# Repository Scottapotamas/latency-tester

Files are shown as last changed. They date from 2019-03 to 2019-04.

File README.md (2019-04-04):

# Latency Tester

Small and simple board to make testing response times easier. Its basically a nice switch, phototransistor and some LEDs with IO.

Intended to be used for measuring:

- Display input latency (switch to photon time)

- Micro/Computer communications latency (switch to serial, serial to photon, etc)

- "Whole chain" timing assessments (key-switch to photon while over communications link etc)
- Human response time tests? Press the button when the light comes on...

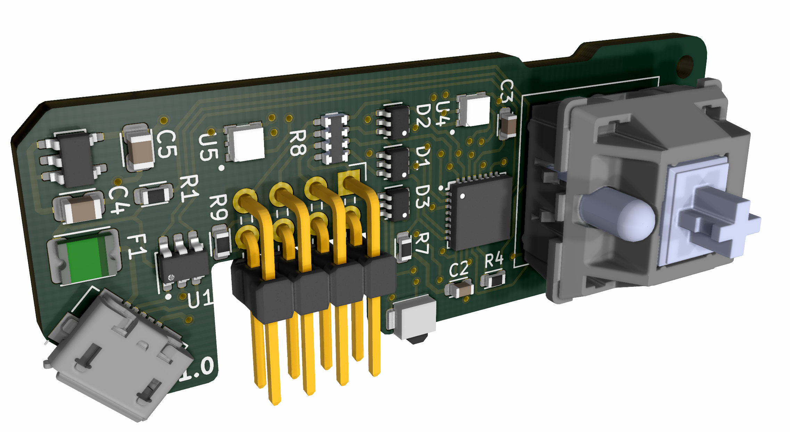
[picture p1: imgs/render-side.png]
render-side


## Electronics

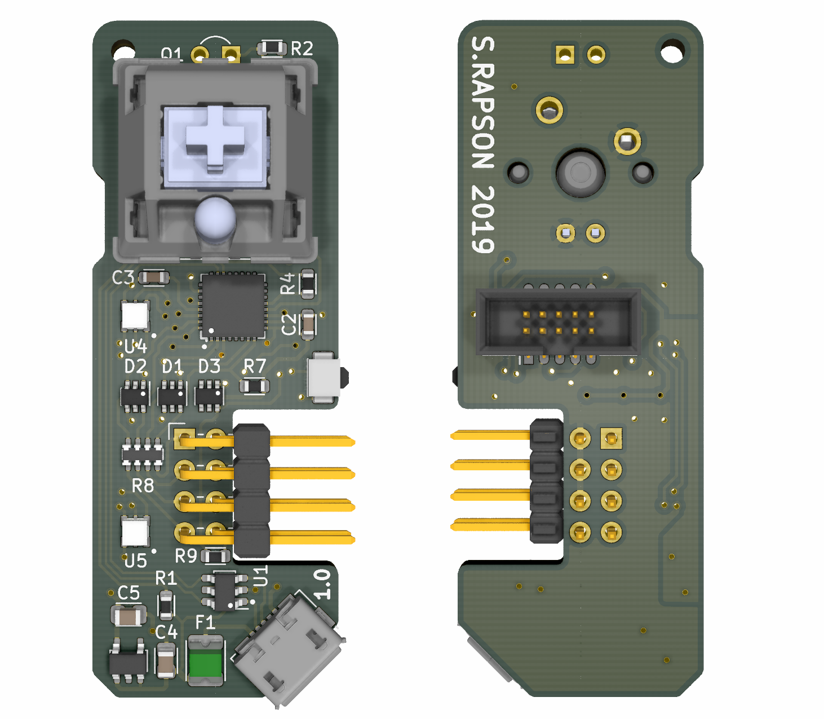
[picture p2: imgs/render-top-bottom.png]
render-top-bottom


- Board uses an ATSAMD M0 microcontroller. Intended for use with the Adafruit Trinket bootloader/ecosystem.

- Native USB means it can enumerate as a HID device, allowing use as a mouse/keyboard etc, or USB CDC.

- Cherry MX key-switch to act as the 'stimulus'. Photo-sensor to measure display changes as required.

- Expansion IO header provides hardware UART, along with 2 IO lines primarily intended to signal the stimulus and optical detection times. This 2x4 2.54mm header can be connected directly into a Saleae Logic analyser for timing analysis.

- 2x APA102 RGB Leds can be used to indicate state etc.
- 3mm LED in MX keyswitch is connected to the `LED_BUILTIN` pin for Arduino ecosystem, indicates bootloader state and can be used as generic user LED.
- Reset switch on bottom edge.
- SWD connector on rear isn't intended to be populated.

## Enclosure

Mostly designed to try some new modelling techniques and different enclosure approach. Intended for SLA 3D printing. I used [Lexcent](http://www.lexcent.com/).

Consists of two parts. Board slides into the halves, though some minor sanding/filing might be required depending on tolerances of SMD component placement.

I'll probably paint the 'bottom' part black, with the 'diffuse white' natural plastic allowing the top section to act as an illuminated highlight strip as depicted in the render.

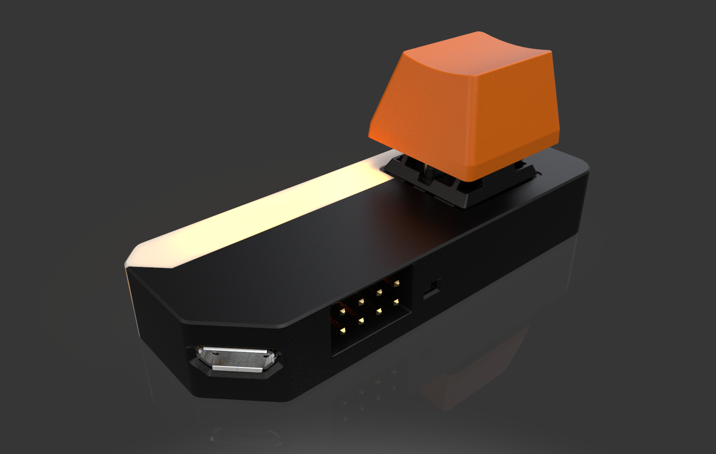
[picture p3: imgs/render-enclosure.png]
render-enclosure


## Firmware

TBD.

## Software

TBD

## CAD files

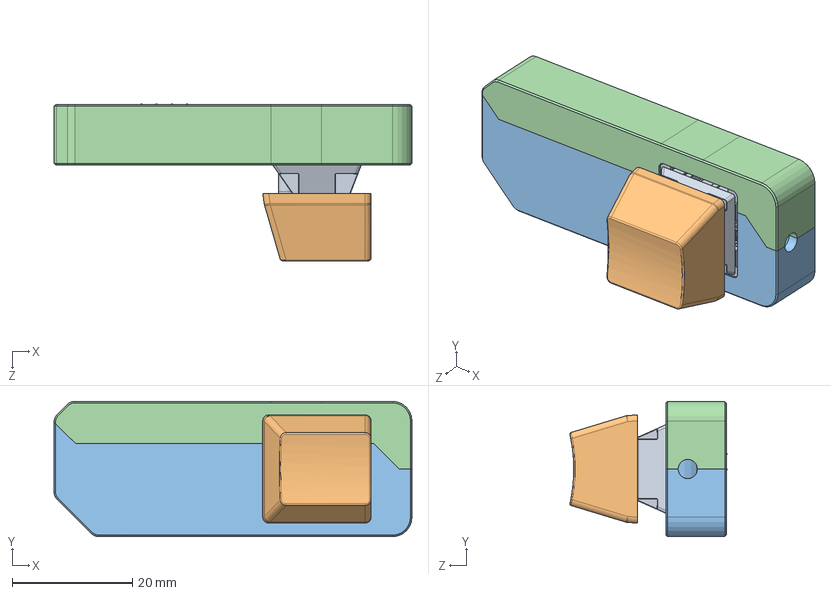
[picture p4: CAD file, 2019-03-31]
mcad/latency-tester-assy.SLDASM
59.5 x 22.5 x 26.2 mm
reflex_pcb
mx-keycap
shell-top

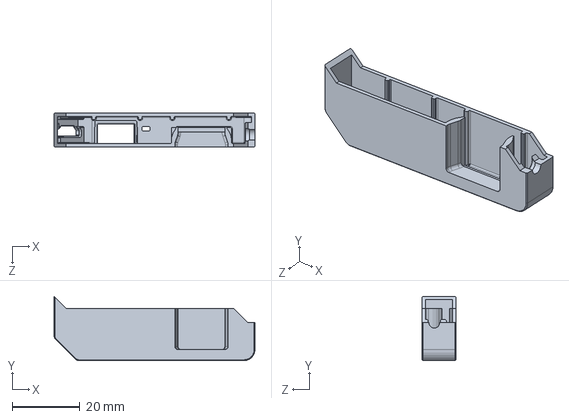
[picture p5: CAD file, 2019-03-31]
mcad/shell.SLDPRT
59.5 x 19.0 x 10.0 mm

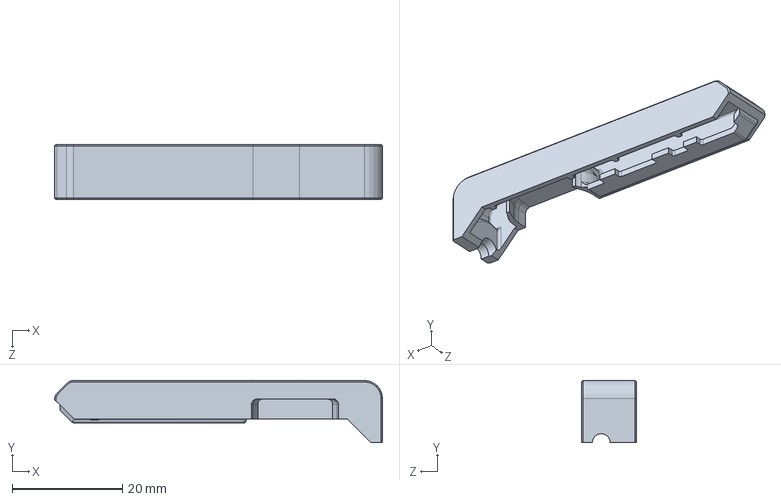
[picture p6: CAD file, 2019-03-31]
mcad/shell-top.SLDPRT
59.5 x 11.2 x 10.0 mm

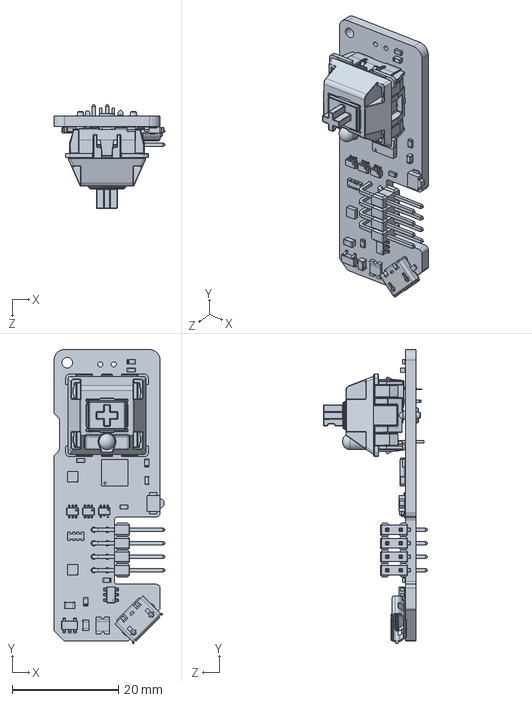
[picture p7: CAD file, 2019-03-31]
mcad/reflex_pcb.SLDPRT
20.9 x 55.4 x 19.6 mm

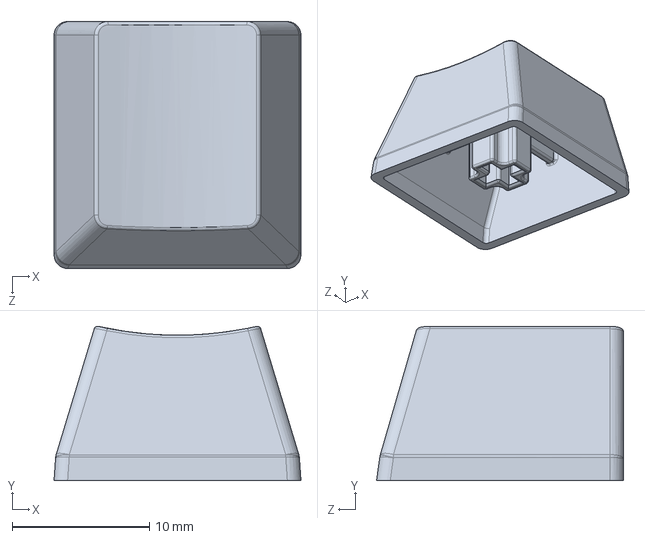
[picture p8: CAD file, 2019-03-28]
mcad/mx-keycap.SLDPRT
18.0 x 11.3 x 18.0 mm

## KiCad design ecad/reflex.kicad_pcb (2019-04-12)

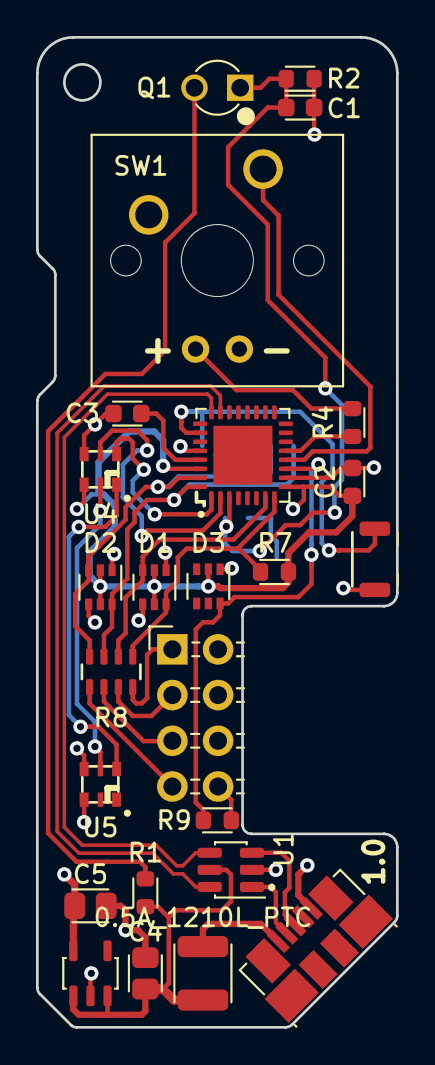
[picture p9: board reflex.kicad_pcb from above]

Board: 2 copper layers, 20.0 x 55.0 mm, 26 parts (1 on the bottom side), 29 nets.

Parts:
C1: 1n_X7R_1608M; CAPC1608X90N
C2: 1u_X7R_1608M; CAPC1608X90N
C3: 100n_X7R_1608M; CAPC1608X90N
C4, C5: 10u_X7R_2012M; CAPC2012X110N
D1, D2, D3: BAV99_DUAL; SOT-363-6N
F1: 0.5A_1210L_PTC; FUSC3225X85L50N
J1: USB_MICRO_B_SMD_2; MOLEX_47346-0001
J2: CONN_02X04_RA; CONN_02X04_RA_MALE
Q1: BPW85C; TRANS_BCW85
R1: 0R_1608M; RESC1608X50N
R2, R7: 10K0_1608M; RESC1608X50N
R4, R9: 1K50_1608M; RESC1608X50N
R8: 100R_QUAD_ARRAY_1608M; R_Array_Concave_4x1608M
SW1: CHERRY_MX1A-E1NW_BLUE; CHERRY_MX_PCB
SW2: B3U-3000P_SPST-NO_SMD; B3U-3000P
U1: USBLC6; SOT95P280X145-6L50N
U2: ATSAMD21E18A; QFN33P50_500X500X100L40X24T345N
U3: AP2112K-3.3; SOT95P280X145-5L30N
U4, U5: APA102-2020; AP102_200X200X90L
X1: SWD_SMT_SOCKET; CNCTECH_3220-10-0300-00

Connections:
+3.3V: C2.2, C5.1, D1.2, D1.5, D2.2, D2.5, D3.2, R7.2, U2.9, U2.30, U3.5, U4.5, U5.5, X1.1
+5V: C4.1, F1.1, R1.1, U1.5, U3.1, U3.3
EXTERNAL_TRIG: D3.6, R9.2, U2.11
GND: C1.2, C2.1, C3.1, C4.2, C5.2, D1.1, D1.4, D2.1, D2.4, D3.1, J1.5, J2.6, J2.7, J2.8, R2.1, SW1.2, SW1.4, SW2.1, U1.2, U2.10, U2.28, U3.2, U4.4, U5.4, X1.3, X1.5
LED_CLK: U2.2, U4.3
LED_DATA: U2.1, U4.2
unnamed: C3.2, U2.29
unnamed: F1.2, J1.1
unnamed: J1.2, U1.1
unnamed: J1.3, U1.3
unnamed: J2.1, R8.4
unnamed: J2.2, R8.3
unnamed: J2.3, R8.2
unnamed: J2.4, R8.1
unnamed: J2.5, R9.1
unnamed: Q1.C, R1.2
unnamed: R4.1, SW1.3
unnamed: U4.1, U5.2
unnamed: U4.6, U5.3
PHOTO_TRANS: C1.1, Q1.E, R2.2, U2.3
STATUS_CAPTURE: D2.3, R8.8, U2.31, X1.4
STATUS_TRIGGER: D2.6, R8.7, U2.32, X1.2
STATUS_USER: R4.2, U2.13
SWITCH_TRIG: SW1.1, U2.12
UART_RX: D1.6, R7.1, R8.5, U2.8
UART_TX: D1.3, R8.6, U2.7
USB_D+: U1.4, U2.24
USB_D-: U1.6, U2.23
~RESET: SW2.2, U2.26, X1.10

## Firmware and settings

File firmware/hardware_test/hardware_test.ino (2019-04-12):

#include <Adafruit_DotStar.h>
#include <SPI.h>

#define PIN_BUTTON 2
#define PIN_PHOTOSENSE 0
#define PIN_STATUS 13

#define PIN_RGB_DATA   7
#define PIN_RGB_CLOCK  8
#define NUM_PIXELS 2

Adafruit_DotStar strip = Adafruit_DotStar( NUM_PIXELS, PIN_RGB_DATA, PIN_RGB_CLOCK, DOTSTAR_BRG );

void setup_pins()
{
  pinMode( PIN_BUTTON,      INPUT_PULLUP  );
  pinMode( PIN_PHOTOSENSE,  INPUT         );
  pinMode( PIN_STATUS,      OUTPUT        );

  //use the full capability of the ARM M0 ADC
  analogReadResolution(12); 
}

void setup()
{
  Serial.begin(115200);

  setup_pins();
  
  strip.begin(); // Initialize pins for output
  strip.show();  // Turn all LEDs off ASAP
}

uint8_t  hue = 0;

uint16_t light_adc = 0;
bool button_pressed = 0;

void loop()
{
  // Sample inputs
  light_adc       = analogRead( PIN_PHOTOSENSE );
  button_pressed  = !digitalRead( PIN_BUTTON );
  
  //turn the status led on when the button is pressed
  digitalWrite( PIN_STATUS, !button_pressed );
  
  if( button_pressed )
  {
    hue += 15; //abuse the fact that it rolls over
  }
  // run the two leds 180deg out of phase
  strip.setPixelColor(0, Wheel(hue));
  strip.setPixelColor(1, Wheel(hue));

  strip.show(); 
  delay(50);
}

// Hue transition on a 8-bit position value, returns RGB
uint32_t Wheel(byte WheelPos) {
  WheelPos = 255 - WheelPos;
  
  if(WheelPos < 85) 
  {
    return strip.Color(255 - WheelPos * 3, 0, WheelPos * 3);
  }
  
  if(WheelPos < 170) 
  {
    WheelPos -= 85;
    return strip.Color(0, WheelPos * 3, 255 - WheelPos * 3);
  }
  
  WheelPos -= 170;
  return strip.Color(WheelPos * 3, 255 - WheelPos * 3, 0);
}

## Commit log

2019-03-25 Adds base files for PCB
    [reflex.kicad_pcb, reflex.sch]
2019-03-25 Adds bulk of schematic parts
    [reflex.sch]
2019-03-25 Schematic changes, pcb layout
    Rough layout concepts established, started test routing
    [reflex.kicad_pcb, reflex.sch]
2019-03-26 Continued placement concepts and packaging ideas
    [reflex.kicad_pcb, reflex.sch]
2019-03-26 Routing completed
    [reflex.kicad_pcb, reflex.sch]
2019-03-26 Board outline cleanup, cosmetics
    [reflex.kicad_pcb]
2019-03-26 Comments on PCB file
    [reflex.kicad_pcb]
2019-03-28 Adds step model
    [reflex.kicad_pcb]
2019-03-28 Adds gerber exports
    [reflex-B.Cu.gbl, reflex-B.Mask.gbs, reflex-B.SilkS.gbo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]
2019-03-28 First pass 3D printable enclosure
    For SLA printing. Two halves
    [latency-tester-assy.SLDASM, mx-keycap.SLDPRT, reflex_pcb.SLDPRT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]
2019-03-31 Shell refinement pass
    [latency-tester-assy.SLDASM, reflex_pcb.SLDPRT, shell-top.SLDPRT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]
2019-03-31 Shell changes to make sure things fit
    [latency-tester-assy.SLDASM, shell-top.SLDPRT, shell.SLDPRT]
2019-04-04 Adds PCB/enclosure renders and README
2019-04-12 Fixed incorrect USB pinout to microcontroller
    Caught with prototype boards :(
    [reflex.kicad_pcb, reflex.sch]
2019-04-12 Super simple firmware test
    When button is down, both RGB leds cycle through the rainbow.
